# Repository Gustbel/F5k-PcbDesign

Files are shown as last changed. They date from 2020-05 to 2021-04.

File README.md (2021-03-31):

# Diseño en ALTIUM del PCB del FROST5000 - Versión RTM 1.0 #

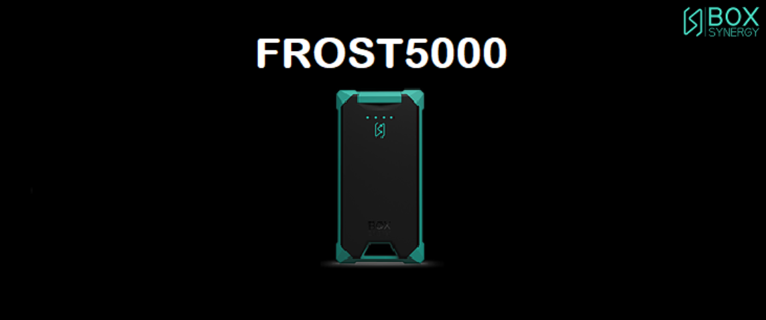
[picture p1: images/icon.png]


## Frost5000 PCB 3D - Versión RTM 1.0 

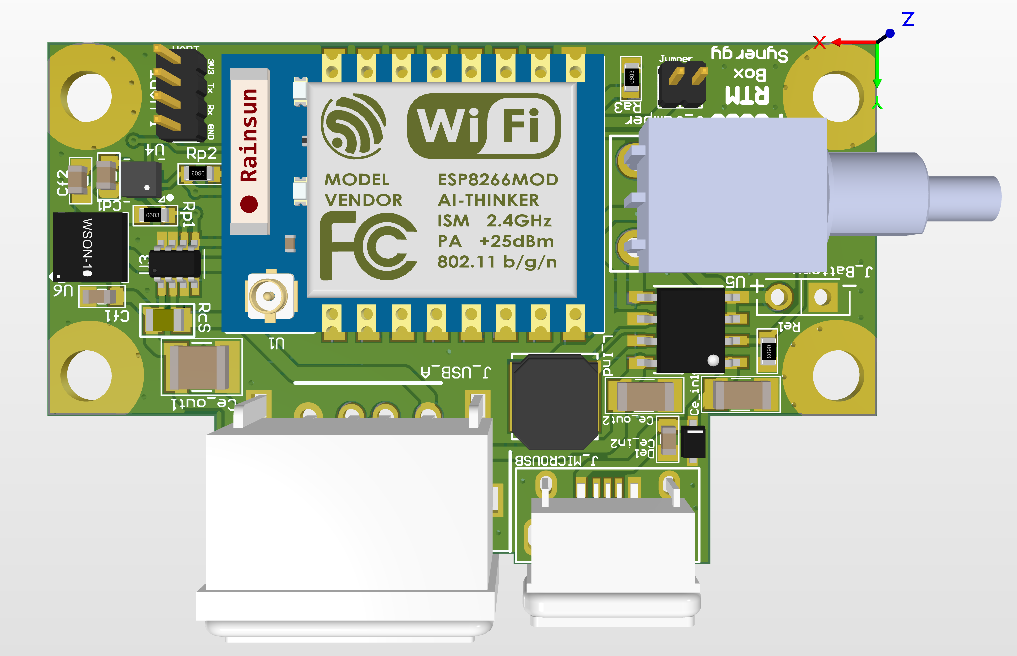
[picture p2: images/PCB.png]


## ¿Para que es este repositorio? 

 - Este repositorio servirá para tener un **Control de Versiones**, **Acceso Remoto al developer** y **Permitir Acceso continuo de avances** al equipo de trabajo de *Box Synergy*.

## ¿Como funciona este repositorio?

Este repositorio tiene dos Branches (o Ramas):

* **master:** Contiene la última versión estable, es decir después de cumplir un objetivo en el diseño y se compruebe que fue estable, se hace un salvado de datos en esta rama. Para consultar avances es preferible mirar esta rama ya que es la más estable.
* **develop:** Contiene la versión que está en desarrollo, por lo tanto probablemente inestable y con errores naturales durante el proceso de desarrollo. Esta rama es la utilizada por el desarrollador y por algún colaborador que quiera mirar o ayudar en pleno desarrollo.

## ¿Como puedo consultar el proyecto?
1. Si no lo tiene, instalar cualquier versión de Altium Designer en su PC.
2. Posicionese en el **BRANCH** (o rama) que usted desee descargar. Para seleccionar el branch haga click en el menú desplegable que está debajo del título del Repositorio (mas específicamente debajo de la descripción del repositorio) y elija el Branch que usted desee.
3. Descargar este repositorio desde un botón con tres puntos **(...)** que se encuentra en la esquina superior derecha del repositorio (al lado del botón *Clone*), luego seleccione ***Download Repository***. Se descargará un archivo comprimido *.zip*.
4. Descomprima la carpeta del Repositorio en alguna carpeta conocida.
5. Abra Altium y seleccione el proyecto que acaba de descomprimir.

## Consultas
- electronic@box-synergy.com	---  Contacto Área Electrónica de Box Synergy
- gustavobelbruno@gmail.com		---  Contacto Gustavo Belbruno - Summits 7 Beta Project Main Designer

																					Repository created 05/04/2020

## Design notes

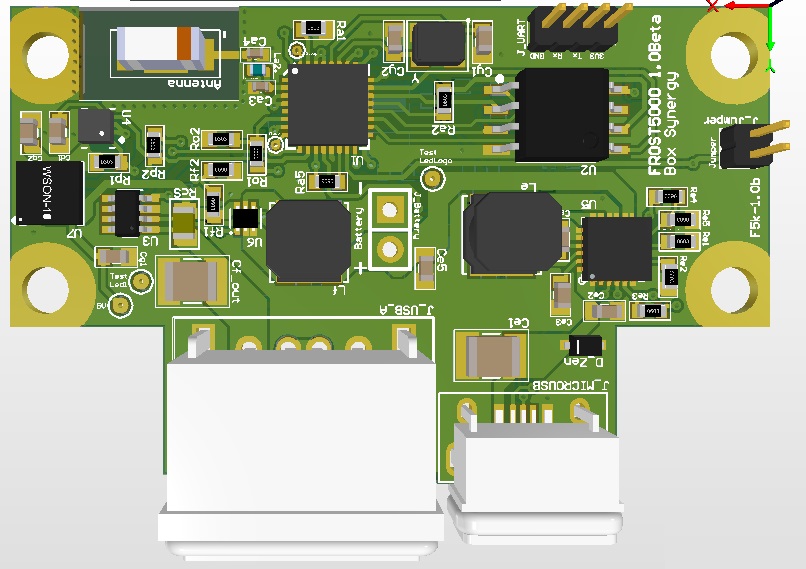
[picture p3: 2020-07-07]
images/PCBFinal_F5k_ConAntenaCeramica.jpg

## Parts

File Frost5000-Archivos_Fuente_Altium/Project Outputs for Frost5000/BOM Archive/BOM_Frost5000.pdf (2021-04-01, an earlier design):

## BOM_Frost5000

1

Component List / BOM Archive | Company: | Box Synergy
Project: | Frost 5000 | Location: | Córdoba, Argentina
Version: | RTM 1.0 | Website: | https://www.box-synergy.com/
Report Date: | 03-29-2021 | Design Engineer Contact: | electronic@box-synergy.com - Gustavo Belbruno
Generated by: | Gustavo Belbruno - Box Synergy Engineering Area
# | Designator | Name/Value | Description | Package / Case | Importance* | Quantity | Manufacturer | Supplier 1 | Alternative Supplier

Name | Part Number | Link Part | Name | Part Number | Link Part
1, 3 | Ca1, Cd1 | 0.1uF | Capac Ceramic SMD 0603 | 0603 | | 2 | - | - | - | - | - | - | -
2 | Ca2 | 10uF | Capac Ceramic SMD 1206 | 1206 | | 1 | - | - | - | - | - | - | -
4, 8, 11 | Ce_bat, Ce_out2, Cf_bat1 | 22uF 10V | Capac Ceramic SMD 1206 | 1206 | | 3 | - | - | - | - | - | - | -
5, 13, 14 | Ce_in1, Cu1, Cu2 | 10uF 10V | Capac Ceramic SMD 1206 | 1206 | | 3 | - | - | - | - | - | - | -
6, 12 | Ce_in2, Cf_bat2 | 100nF 10V | Capac Ceramic SMD 0603 | 0603 | | 2 | - | - | - | - | - | - | -
7 | Ce_out1 | 22uF 10V | Capac Ceramic SMD 1210 | 1210 | | 1 | - | - | - | - | - | - | -
9 | Cf1 | 22uF 10V | Capac Ceramic SMD 0603 | 0603 | | 1 | - | - | - | - | - | - | -
10 | Cf2 | 22uF | Capac Ceramic SMD 0603 | 0603 | | 1 | - | - | - | - | - | - | -
37 | Rd1 | 4.7K | Resistor SMD | 0603 | | 1 | - | - | - | - | - | - | -
33, 34, 35, 38, 44 | Ra1, Ra2, Ra3, Re1, Rpb1 | 5.6K | Resistor SMD | 0603 | | 5 | - | - | - | - | - | - | -
45, 47, 49, 51, 53 | Rq1b, Rq2b, Rq3b, Rq4b, Rq5b | 1K | Resistor SMD | 0603 | | 5 | - | - | - | - | - | - | -
39, 55 | Rf_in1, Ru | 0 Ohms | Resistor SMD | 0603 | | 2 | - | - | - | - | - | - | -
40 | Ro1 | 332K +-1% | Resistor SMD | 0603 | | 1 | - | - | - | - | - | - | -
41 | Ro2 | 90.9K +- 1% | Resistor SMD | 0603 | | 1 | - | - | - | - | - | - | -
42, 43 | Rp1, Rp2 | 10K | Resistor SMD | 0603 | | 2 | - | - | - | - | - | - | -
46, 48, 50, 52, 54 | Rq1c, Rq2c, Rq3c, Rq4c, Rq5c | 2.74K | Resistor SMD | 0603 | | 5 | - | - | - | - | - | - | -
36 | RcS | ERJ-6BWFR010V | Shunt 0.01 Ohm 0.5W 1% SMD Resistor | 0805 | Important Good Quality, at least 0.5W | 1 | Panasonic | Mouser | 667-ERJ-6BWFR010V | Link Mouser (https://www.mouser.com/ProductDetail/Panasonic/ERJ-6BWFR010V) | Digikey | P.01AQTR-ND | Link Digikey (https://www.digikey.com/product-detail/en/panasonic-electronic-components/ERJ-6BWFR010V/P-01AQTR-ND/1466354)
26 | L_Ind | SRN5040TA-1R0M | Inductor 1uH 5A | Non Standard | Important Good Quality, 1uH Value, at least 5A | 1 | Bourns | Mouser | 652-SRN5040TA-1R0M | Link Mouser (https://www.mouser.com/ProductDetail/Bourns/SRN5040TA-1R0M) | Digikey | SRN5040TA-1R0MCT-ND | Link Digikey (https://www.digikey.com/product-detail/en/bourns-inc/SRN5040TA-1R0M/SRN5040TA-1R0MCT-ND/9653900)
22 | J_Jumper | M50-3530242 | 1.27mm Pin Header 2x1 | 1.27mm Header | | 1 | HARWIN | Mouser | 855-M50-3530242 | Link Mouser (https://www.mouser.com/ProductDetail/Harwin/M50-3530242?qs=%252BdQmOuGyFcFfqfwYQe%2FxZw%3D%3D) | - | - | -
24 | J_UART | M50-3530442 | 1.27mm Pin Header 4x1 | 1.27mm Header | | 1 | HARWIN | Mouser | 855-M50-3530442 | Link Mouser (https://www.mouser.com/ProductDetail/Harwin/M50-3530242?qs=%252BdQmOuGyFcFfqfwYQe%2FxZw%3D%3D) | - | - | -
23 | J_MICROUSB | CQ-MUB-FS8772 | MicroUSB B-type Socket | - | | 1 | Shenzhen Chuangqin Technology | Alibaba | - | Link Alibaba (https://www.alibaba.com/product-detail/Rating-3-AMP-Micro-usb-Jack_60827902326.html) | - | - | -
25 | J_USB_A | CQ-USB-AFFS90 | USB-A Socket | - | | 1 | Shenzhen Chuangqin Technology | Alibaba | - | Link Alibaba (https://www.alibaba.com/product-detail/4-Pin-Waterproof-IPX8-USB-A_62420880597.html) | - | - | -
15, 16, 17, 18, 19 | D_LED1, D_LED2, D_LED3, D_LED4, D_LED5 | LCB TTSD-T2V1-2J8L-Z | Blue LED PLCC-2 | PLCC-2 | | 5 | OSRAM | Mouser | 720-LCBTTSDT2VA116 0 | Link Mouser (https://www.mouser.com/ProductDetail/OSRAM-Opto-Semiconductors/LCB-TTSD-T2V1-2J8L-Z) | - | - | -
20 | De1 | DDZ6V8BSF-7 | Zener 6.5V / 0.5W | SOD323F | | 3 | Diodes | Mouser | 621-DDZ6V8BSF-7 | Link Mouser (https://www.mouser.com/ProductDetail/Diodes-Incorporated/DDZ6V8BSF-7/) | Digikey | DDZ6V8BSF-7 | Link Digikey (https://www.digikey.com/en/products/detail/DDZ6V8BSF-7/DDZ6V8BSF-7DICT-ND/2921380)
28, 29, 30 | Q1, Q2, Q3 | BC817 | Transistor NPN | SOT-23-3 | | 3 | Diodes | Mouser | 621-BC817-40W-7 | Link Mouser (https://www.mouser.com/ProductDetail/Diodes-Incorporated/BC817-40W-7/) | Digikey | BC817-40W-7 | Link Digikey (https://www.digikey.com/en/products/detail/BC817-40W-7/BC817-40WDICT-ND/816560)
31, 32 | Q4, Q5 | BC807 | Transistor PNP | SOT-23-3 | | 2 | Diodes | Mouser | 621-BC807-40-7-F | Link Mouser (https://www.mouser.com/ProductDetail/Diodes-Incorporated/BC807-40-7-F/?qs=rGAXPo9uwV2n5WQ1Pm08Rg%3D%3D) | Digikey | BC807-40-7-F | Link Digikey (https://www.digikey.com/en/products/detail/BC807-40-7-F/BC807-40FCT-ND/717840)
56 | U1 | ESP-07 | ESP07 Module with Antenna Ai-Thinker | - | | 1 | Ai-Thinker | Alibaba | - | Link Alibaba (https://www.alibaba.com/product-detail/Ai-Thinker-ESP-07-ESP8266-Wifi_62009924257.html) | It can be easily found with others Alibaba sellers

## BOM_Frost5000

2

57 | U2 | 24CW1280T-I/OT | EEPROM 128K I2C | SOT-23-5 | 1 | Microchip | Mouser | 579-24CW1280T-I/OT | Link Mouser (https://www.mouser.com/ProductDetail/Microchip-Technology/24CW1280T-I-OT?qs=qSfuJ%252Bfl%2Fd6lIWZGGRvkYA==) | Digikey | 24CW1280T-I/OTCT-ND | Link Digikey (https://www.digikey.com/product-detail/en/microchip-technology/24CW1280T-I-OT/24CW1280T-I-OTCT-ND/9607061)
58 | U3 | INA219BIDCNR | Current Monitor Regulator High-Side 10mA SOT-23-8 | SOT-23-8 | 1 | Texas Instruments | Mouser | 595-INA219BIDCNR | Link Mouser (https://www.mouser.com/ProductDetail/Texas-Instruments/INA219BIDCNR) | Digikey | 296-46420-1-ND | Link Digikey (https://www.digikey.com/product-detail/en/texas-instruments/INA219BIDCNR/296-46420-1-ND/7033594)
59 | U4 | MC3419 | Accelerometer | VFLGA-12 | 1 | MEMSIC | Mouser | 498-MC3419 | Link Mouser (https://www.mouser.com/ProductDetail/MEMSIC/MC3419/?qs=OlC7AqGiEDn8kT%252B18r9wSA%3D%3D) | - | - | -
60 | U5 | FM5324G | Power Battery Management IC | eSOP8L | 1 | FM Shenzen | Yoycart | FM5324G | Link Yoycart (https://www.yoycart.com/Product/630728961250/) | - | - | -
61 | U6 | LM1117LD-3.3/NOPB | LDO Regulator Pos 3.3V 0.8A Texas - WSON8 | WSON8 | 1 | Texas Instruments | Mouser | 926-LM1117LD33NOPB | Link Mouser (https://www.mouser.com/ProductDetail/Texas-Instruments/LM1117LD-33-NOPB) | Digikey | LM1117LD-3.3 /NOPBCT-ND | Link Digikey (https://www.digikey.com/product-detail/en/texas-instruments/LM1117LD-3-3-NOPB/LM1117LD-3-3-NOPBCT-ND/3527179)
27 | PB1 | 800SP9B7M6RE | Push Button 800C | M6 | 1 | E-Switch | Mouser | 612-800-S762 | Link Mouser (https://www.mouser.com/ProductDetail/E-Switch/800SP9B7M6RE) | onlinecomponents.com | 800SP9B7M6RE | Link OC (https://www.onlinecomponents.com/en/e-switch/800sp9b7m6re-11259284.html)
21 | J_Battery | Connx2_Battery | No component
*Importance: Refers to the importance of using the designated component and not a default replacement | This is a critical device and was specially calculated, it should not be exchanged for any device. In case of not obtaining this device, please contact the design engineer.
| If possible, use the supplied device. In case there is difficulty in obtaining it, you can use another one with similar characteristics, but as long as the device has a complete datasheet where its parameters can be consulted.
| This is a regular device and you can choose the device that suits you.

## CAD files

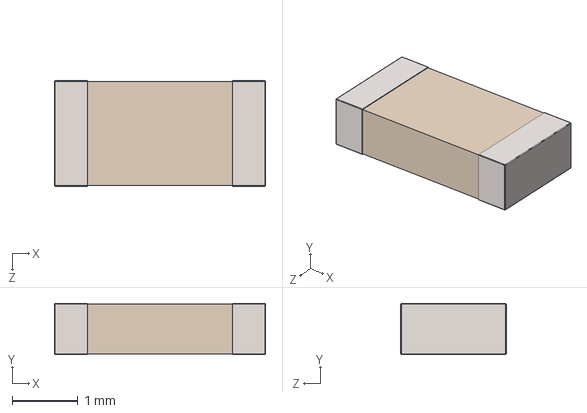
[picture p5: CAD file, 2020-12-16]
Frost5000-Archivos_Fuente_Altium/LibraryUsed/Originales/STEP_Models/Cap1206.step
3.20 x 0.78 x 1.60 mm

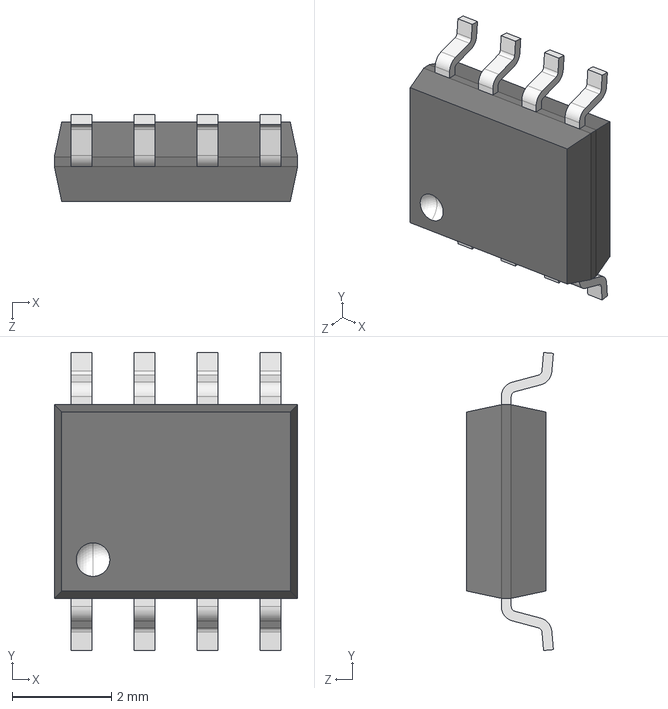
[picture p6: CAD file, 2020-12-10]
Frost5000-Archivos_Fuente_Altium/LibraryUsed/Originales/STEP_Models/SOP8.step
4.90 x 6.00 x 1.75 mm

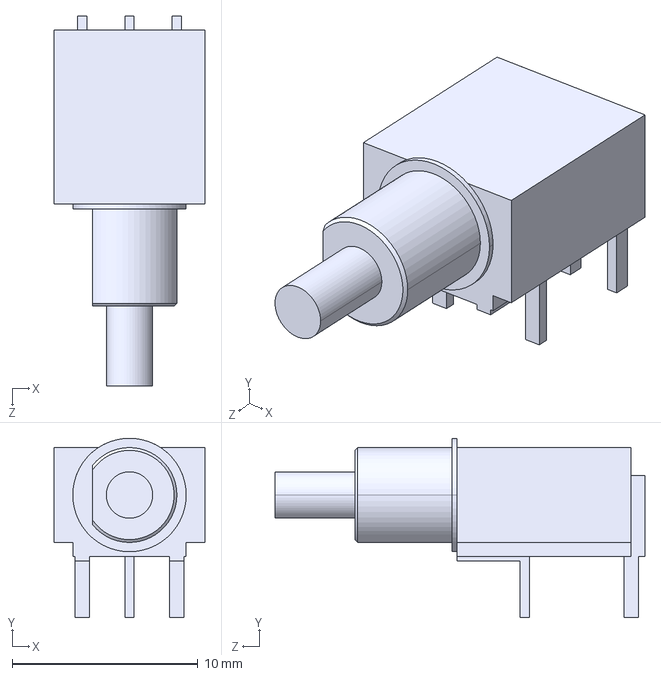
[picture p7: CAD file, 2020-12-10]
Frost5000-Archivos_Fuente_Altium/LibraryUsed/Originales/STEP_Models/Push_800C.STEP
8.10 x 9.65 x 19.9 mm

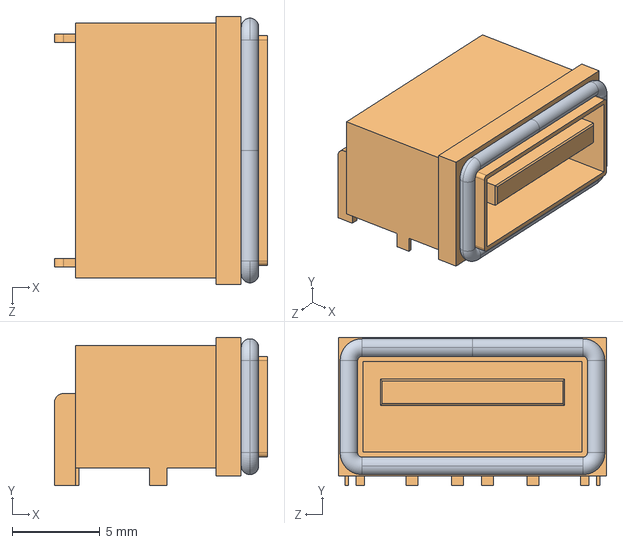
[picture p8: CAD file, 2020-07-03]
Frost5000-Archivos_Fuente_Altium/LibraryUsed/Originales/STEP_Models/USB_A_ip68.STEP
12.1 x 8.45 x 15.3 mm

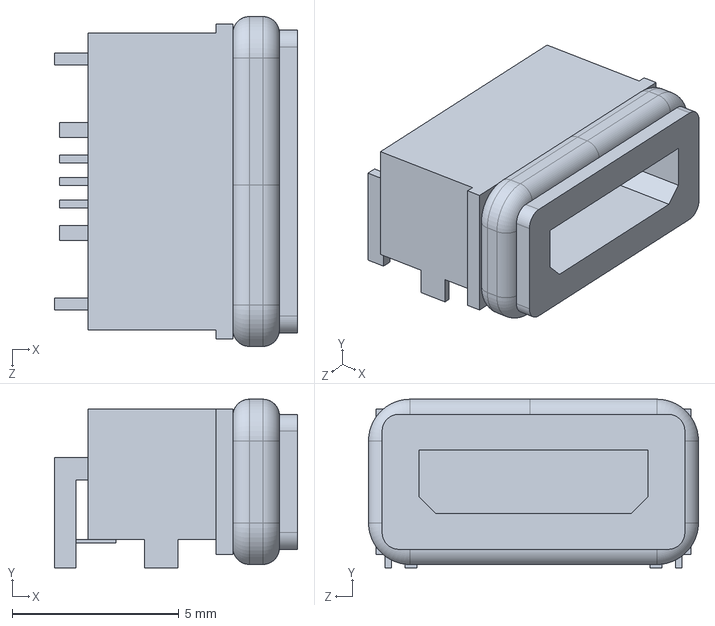
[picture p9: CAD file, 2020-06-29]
Frost5000-Archivos_Fuente_Altium/LibraryUsed/Originales/STEP_Models/MicroUSBip68.STEP
7.29 x 5.06 x 9.90 mm

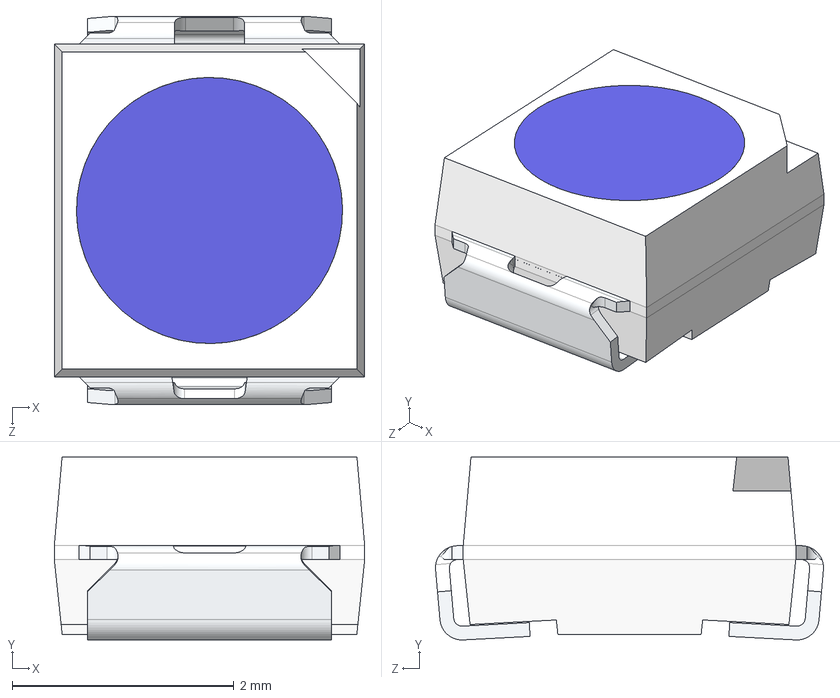
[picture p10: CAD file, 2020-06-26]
Frost5000-Archivos_Fuente_Altium/LibraryUsed/Originales/STEP_Models/LED_PLCC-2.STEP
2.80 x 1.65 x 3.50 mm
PLCC2-Case
TEIL1.stp
LFR1
LFR2

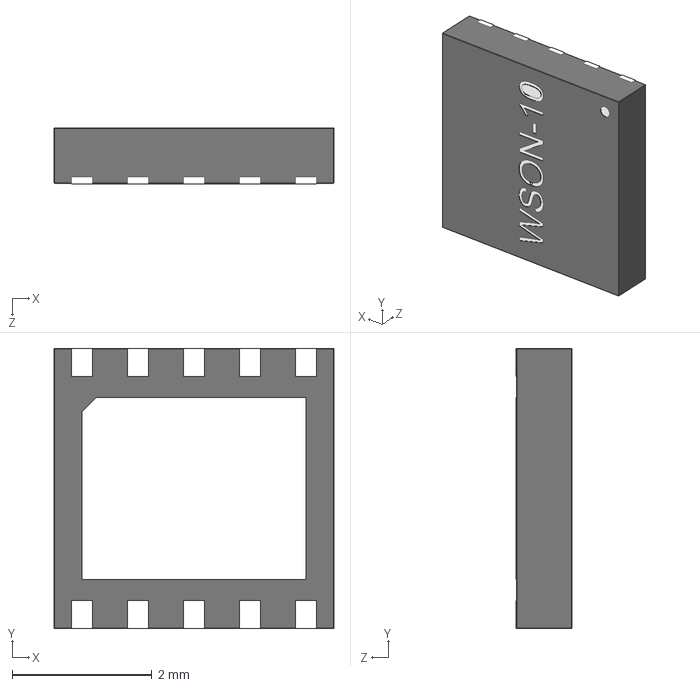
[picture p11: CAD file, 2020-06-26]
Frost5000-Archivos_Fuente_Altium/LibraryUsed/Originales/STEP_Models/LM1117-33-WSON.STEP
4.00 x 4.00 x 0.8 mm

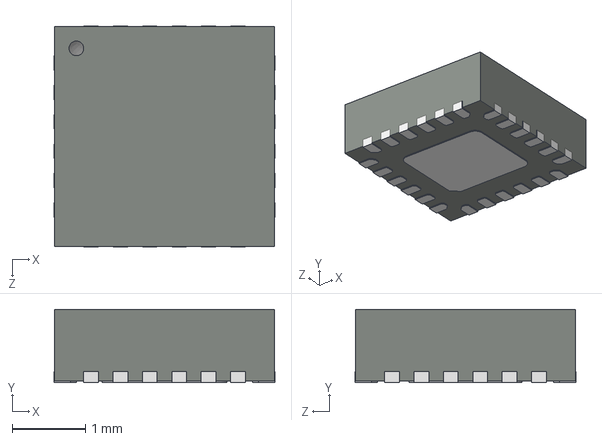
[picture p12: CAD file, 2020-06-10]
Frost5000-Archivos_Fuente_Altium/LibraryUsed/Originales/STEP_Models/ICM-20948.step
3.01 x 1.00 x 3.01 mm

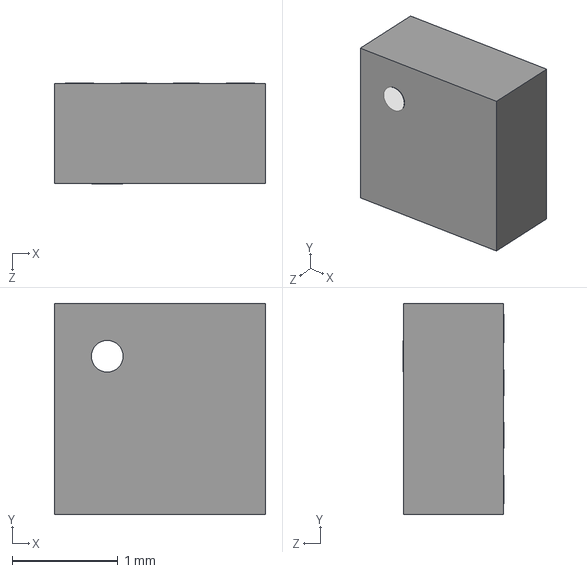
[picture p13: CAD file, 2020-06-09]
Frost5000-Archivos_Fuente_Altium/LibraryUsed/Originales/STEP_Models/LSM303AGR-LGA12.step
2.00 x 2.00 x 0.955 mm

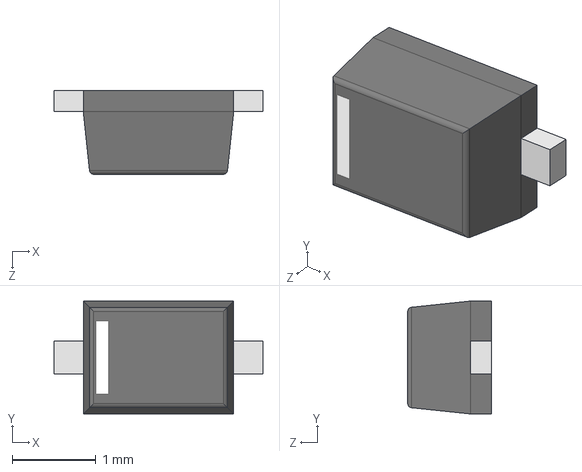
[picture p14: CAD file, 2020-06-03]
Frost5000-Archivos_Fuente_Altium/LibraryUsed/Originales/STEP_Models/Zener-SOD323F.step
2.50 x 1.35 x 1.00 mm

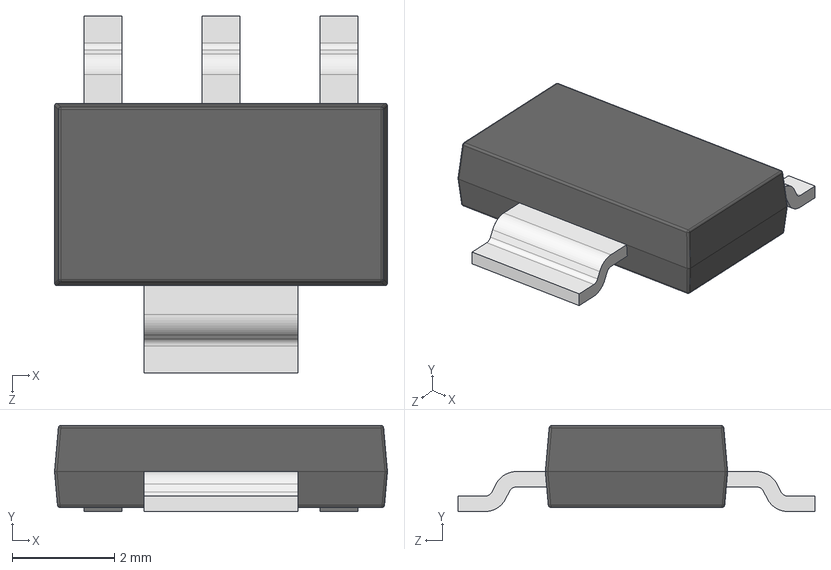
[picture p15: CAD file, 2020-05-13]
Frost5000-Archivos_Fuente_Altium/LibraryUsed/Originales/STEP_Models/LT1171ST-3V3_SOT223.STEP
6.50 x 1.68 x 6.96 mm

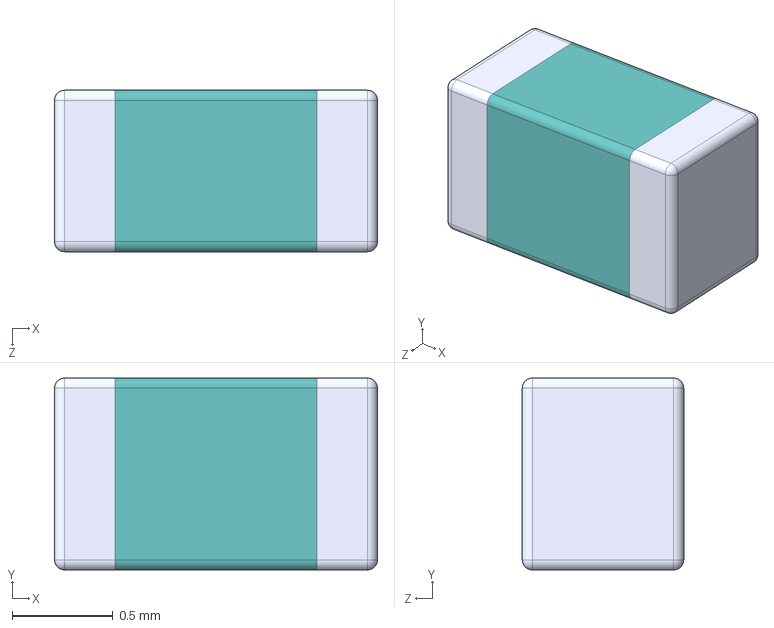
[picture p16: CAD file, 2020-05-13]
Frost5000-Archivos_Fuente_Altium/LibraryUsed/Originales/STEP_Models/Ind0603.step
1.60 x 0.95 x 0.8 mm

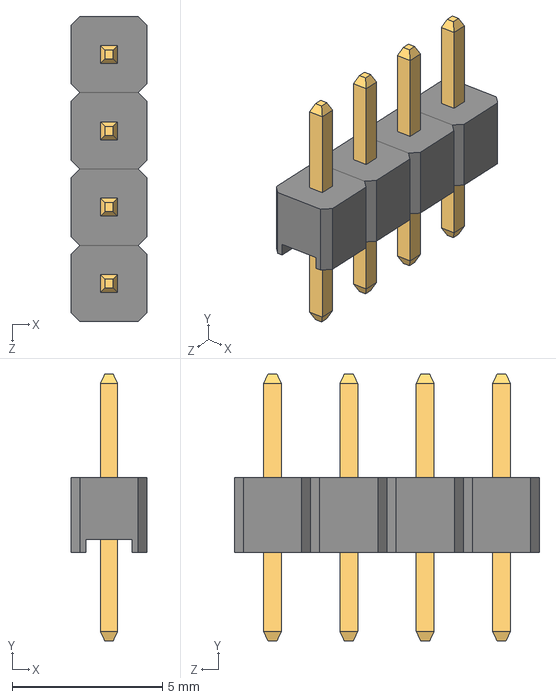
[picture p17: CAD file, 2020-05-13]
Frost5000-Archivos_Fuente_Altium/LibraryUsed/Originales/STEP_Models/Header_254mm_Pitch4-1.step
2.54 x 8.88 x 10.2 mm

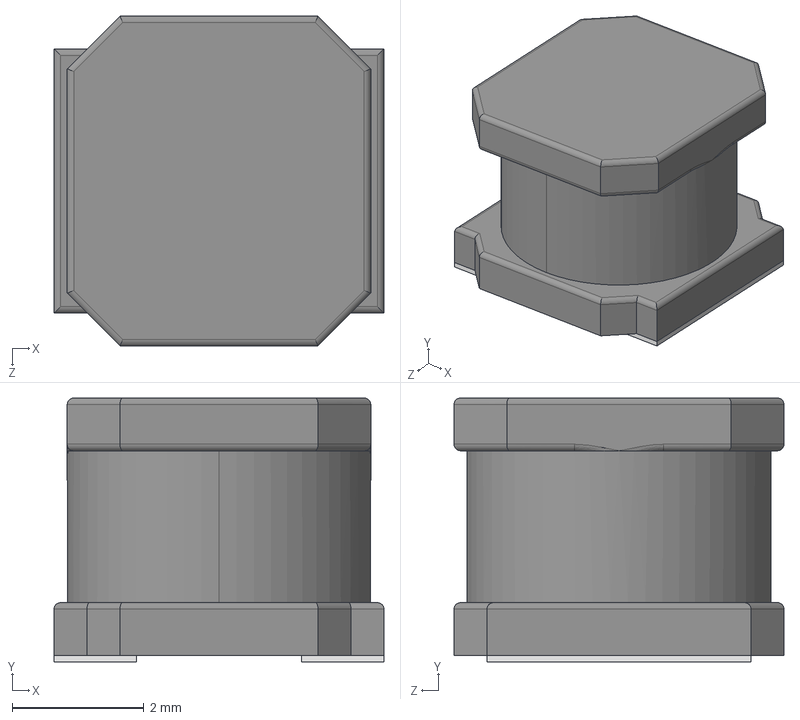
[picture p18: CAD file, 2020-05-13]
Frost5000-Archivos_Fuente_Altium/LibraryUsed/Originales/STEP_Models/Inductor_Buck_SRN5040.step
5.00 x 4.00 x 5.00 mm

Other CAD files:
Frost5000-Archivos_Fuente_Altium/LibraryUsed/Originales/STEP_Models/Cap1210.step
Frost5000-Archivos_Fuente_Altium/LibraryUsed/Originales/STEP_Models/W25Q32JV_SOIC-8-208.STEP
Frost5000-Archivos_Fuente_Altium/LibraryUsed/Originales/STEP_Models/ABM8-26MHz.STEP
Frost5000-Archivos_Fuente_Altium/LibraryUsed/Originales/STEP_Models/Header_127mm_Pitch2-1_usar2.step
Frost5000-Archivos_Fuente_Altium/LibraryUsed/Originales/STEP_Models/BQ25606-VQFN24.step
Frost5000-Archivos_Fuente_Altium/LibraryUsed/Originales/STEP_Models/Cap0603.step
Frost5000-Archivos_Fuente_Altium/LibraryUsed/Originales/STEP_Models/ESP8266EX.STEP
Frost5000-Archivos_Fuente_Altium/LibraryUsed/Originales/STEP_Models/Header_254mm_Pitch2-1.step
Frost5000-Archivos_Fuente_Altium/LibraryUsed/Originales/STEP_Models/INA219_SOT23.STEP
Frost5000-Archivos_Fuente_Altium/LibraryUsed/Originales/STEP_Models/LED_HSMW-C191.STEP
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

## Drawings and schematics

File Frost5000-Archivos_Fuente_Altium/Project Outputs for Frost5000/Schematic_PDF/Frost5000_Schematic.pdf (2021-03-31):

# Current Monitor of USBout

# INA219BIDCNR

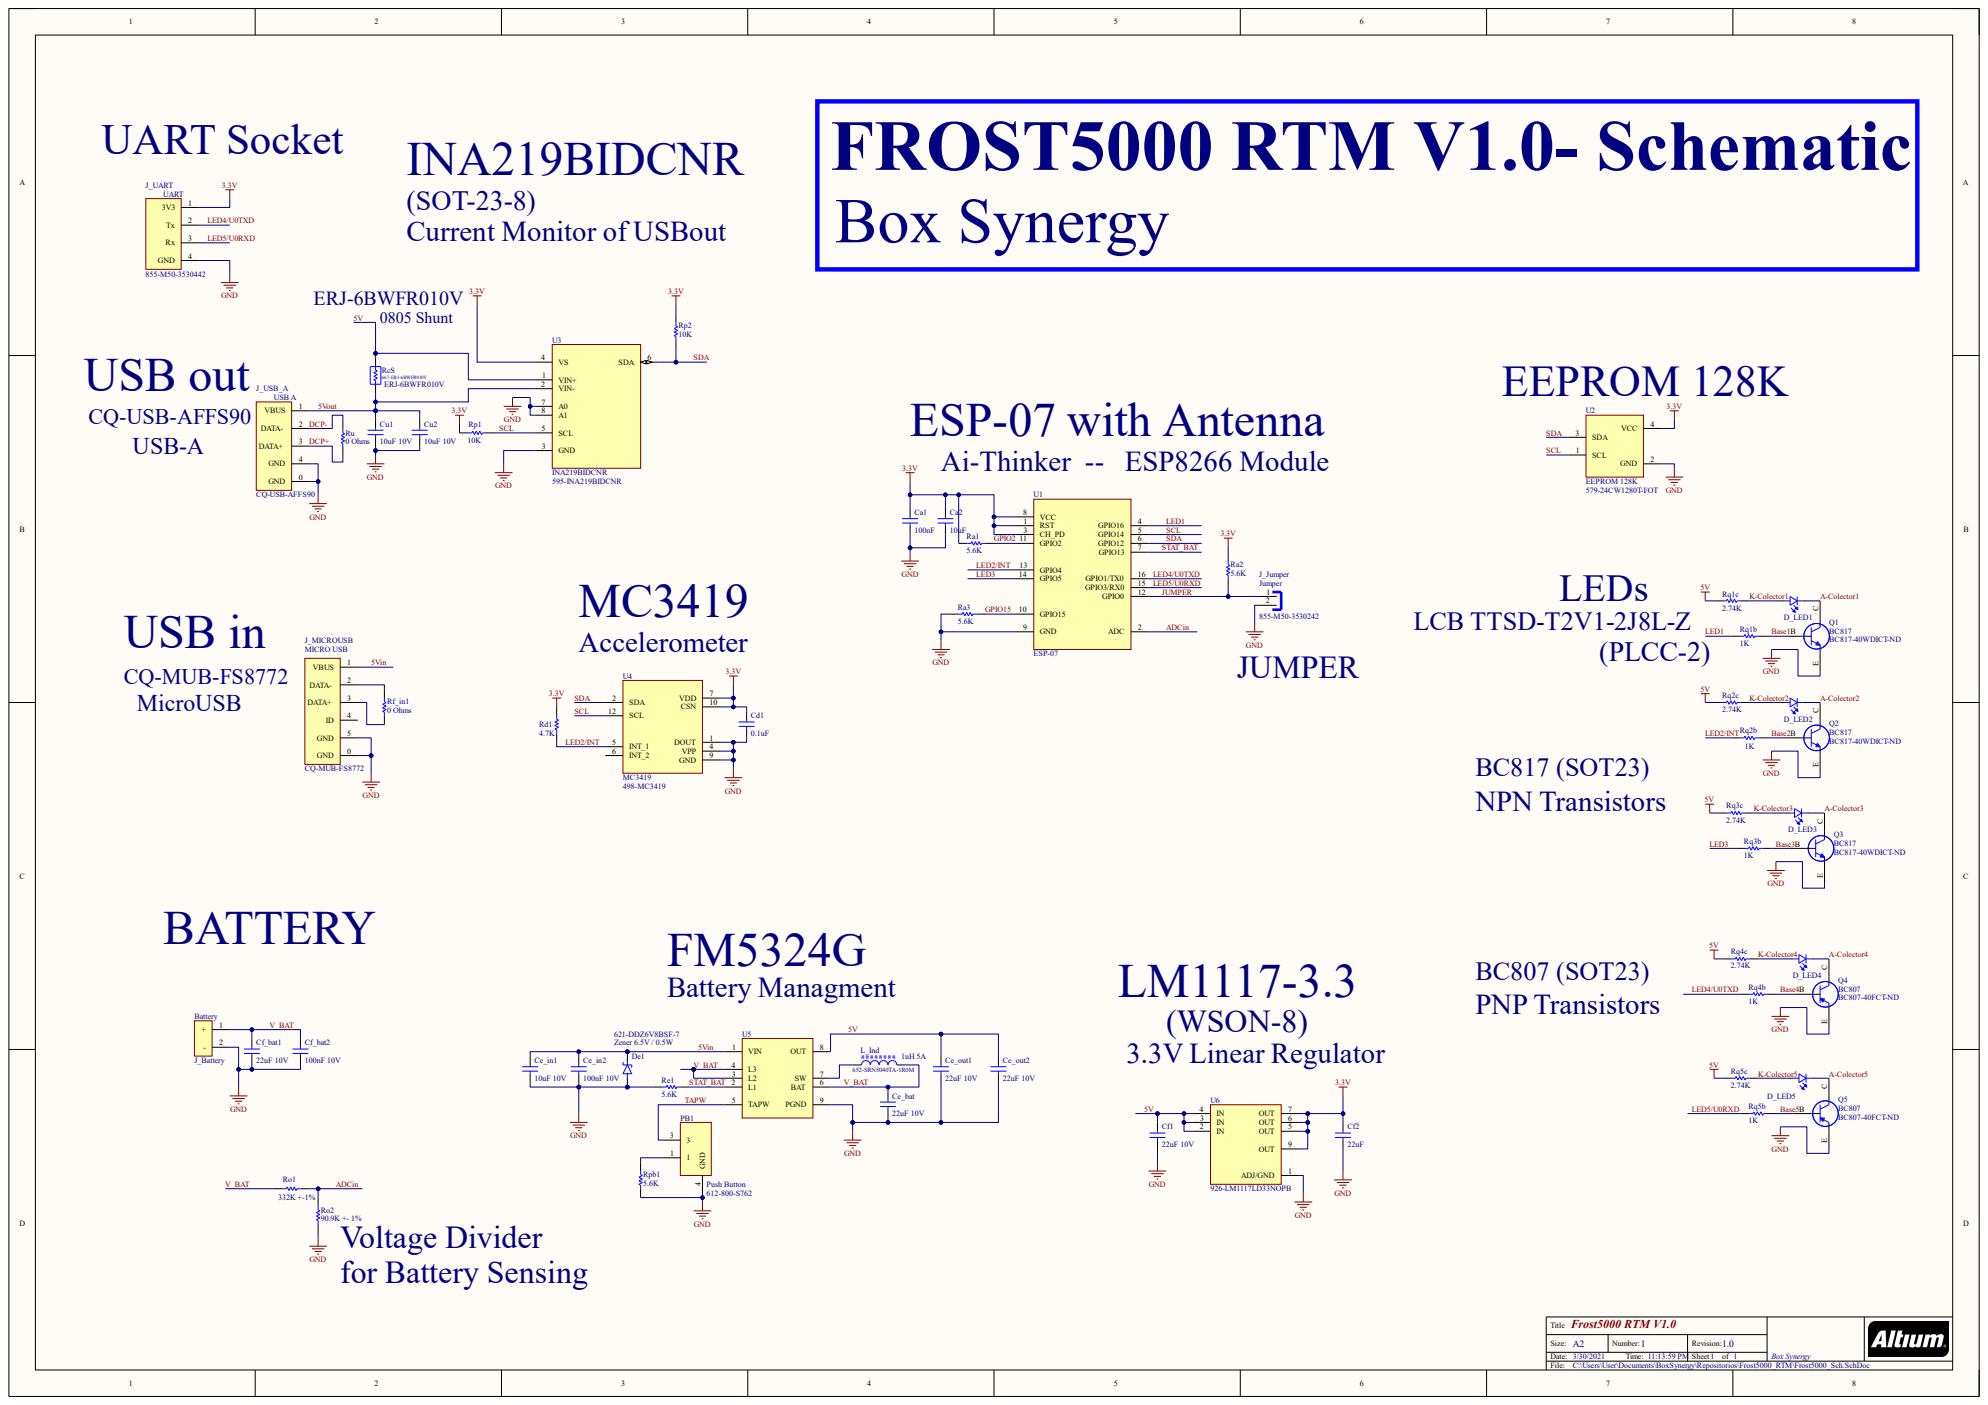
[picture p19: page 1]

Frost5000 RTM V1.0
Title
C:\Users\User\Documents\BoxSynergy\Repositorios\Frost5000_RTM\Frost5000_Sch.SchDoc

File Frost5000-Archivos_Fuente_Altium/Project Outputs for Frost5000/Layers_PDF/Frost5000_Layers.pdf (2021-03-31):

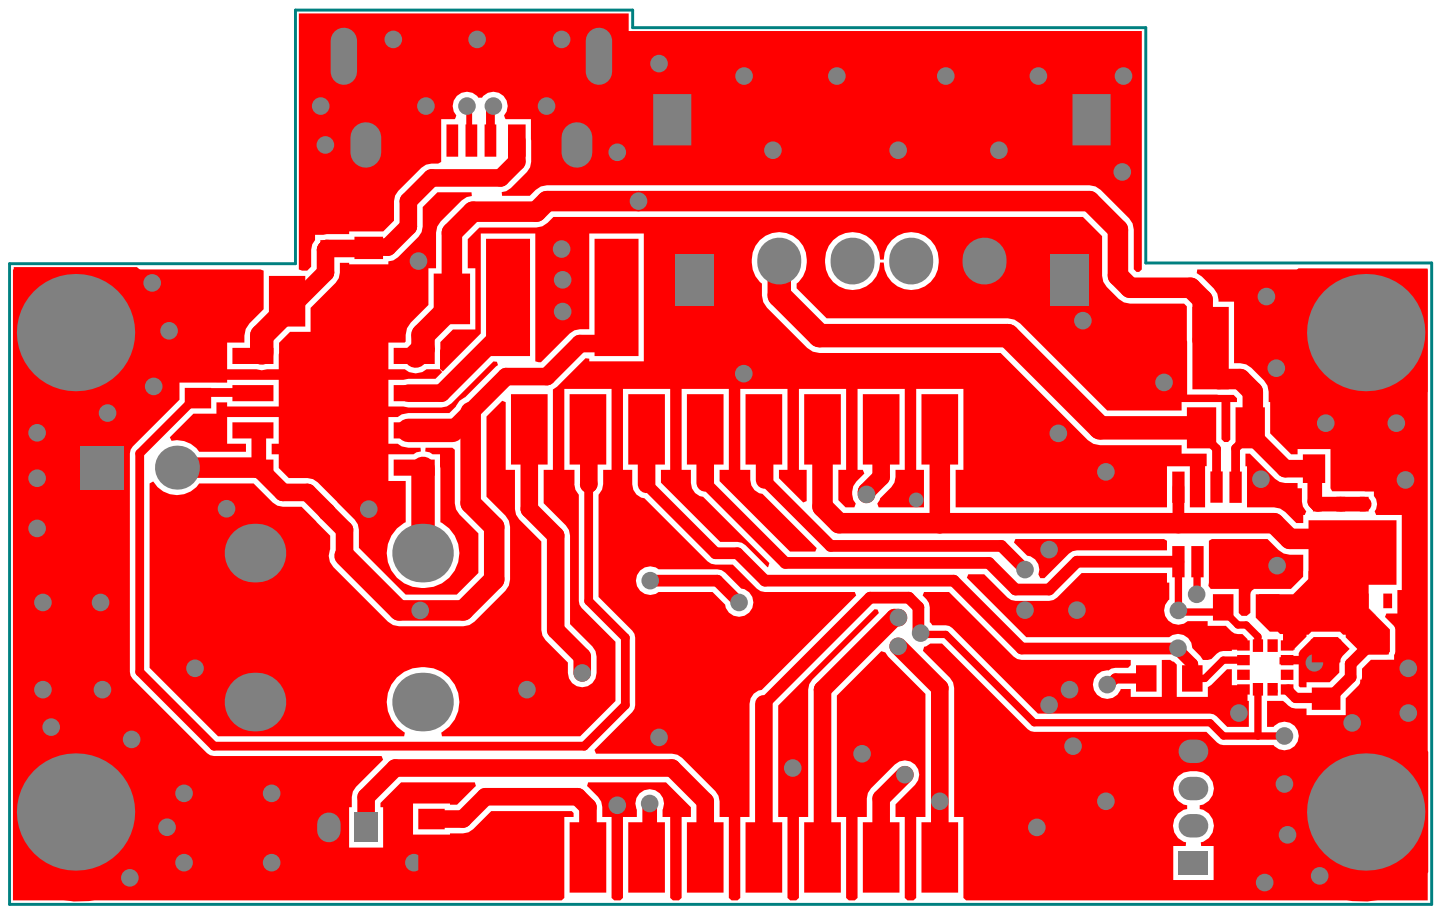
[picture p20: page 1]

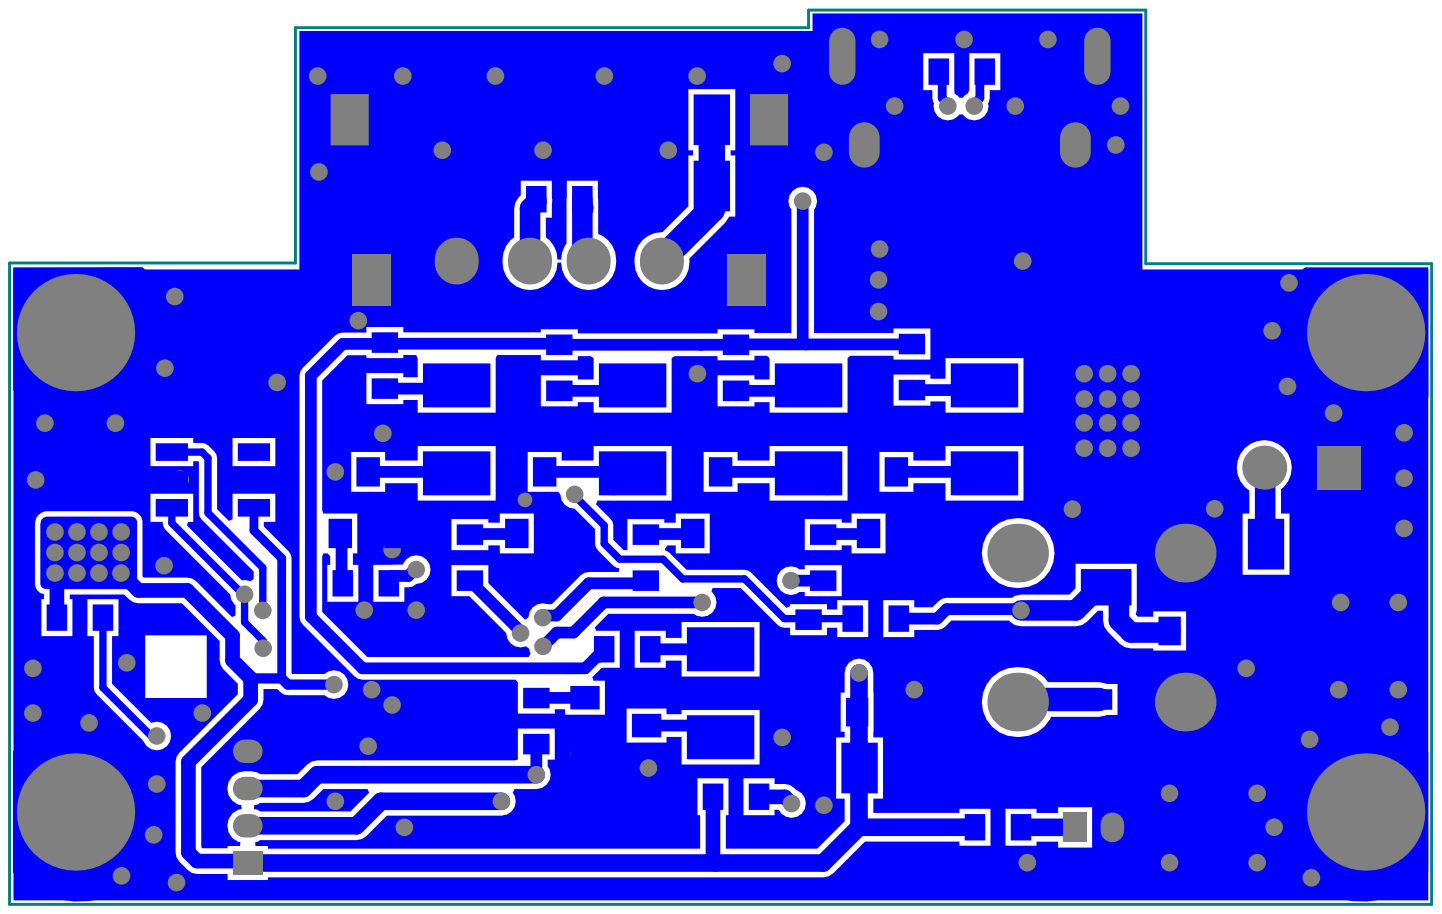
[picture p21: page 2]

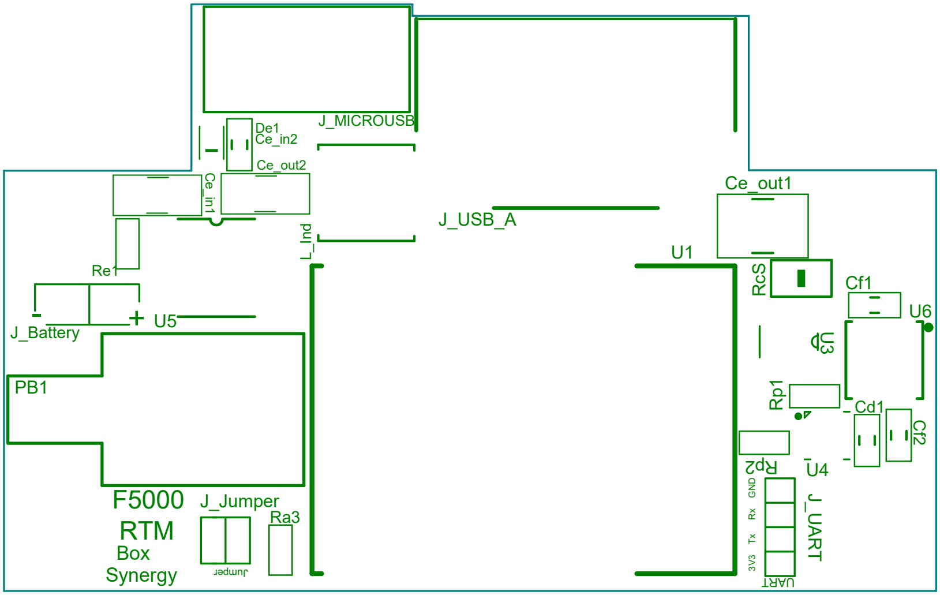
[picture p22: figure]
3V³ Rx GND; Ce_out2; J_Jumper Ce_in1; Ce_out1; J_Battery; J_MICROUSB; F5000 RTM; J_USB_A; Box Synergy
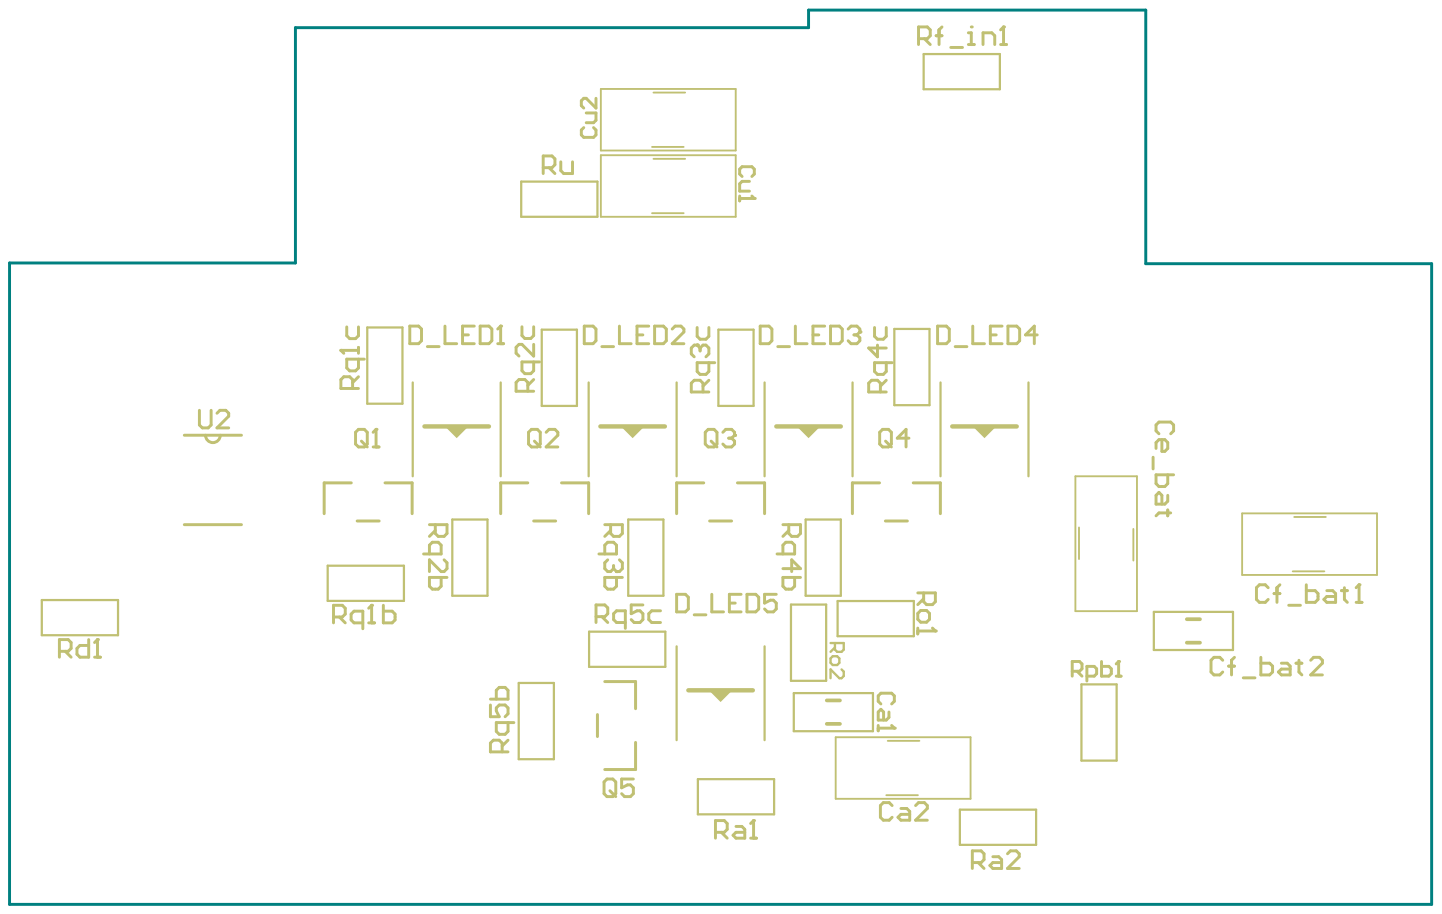
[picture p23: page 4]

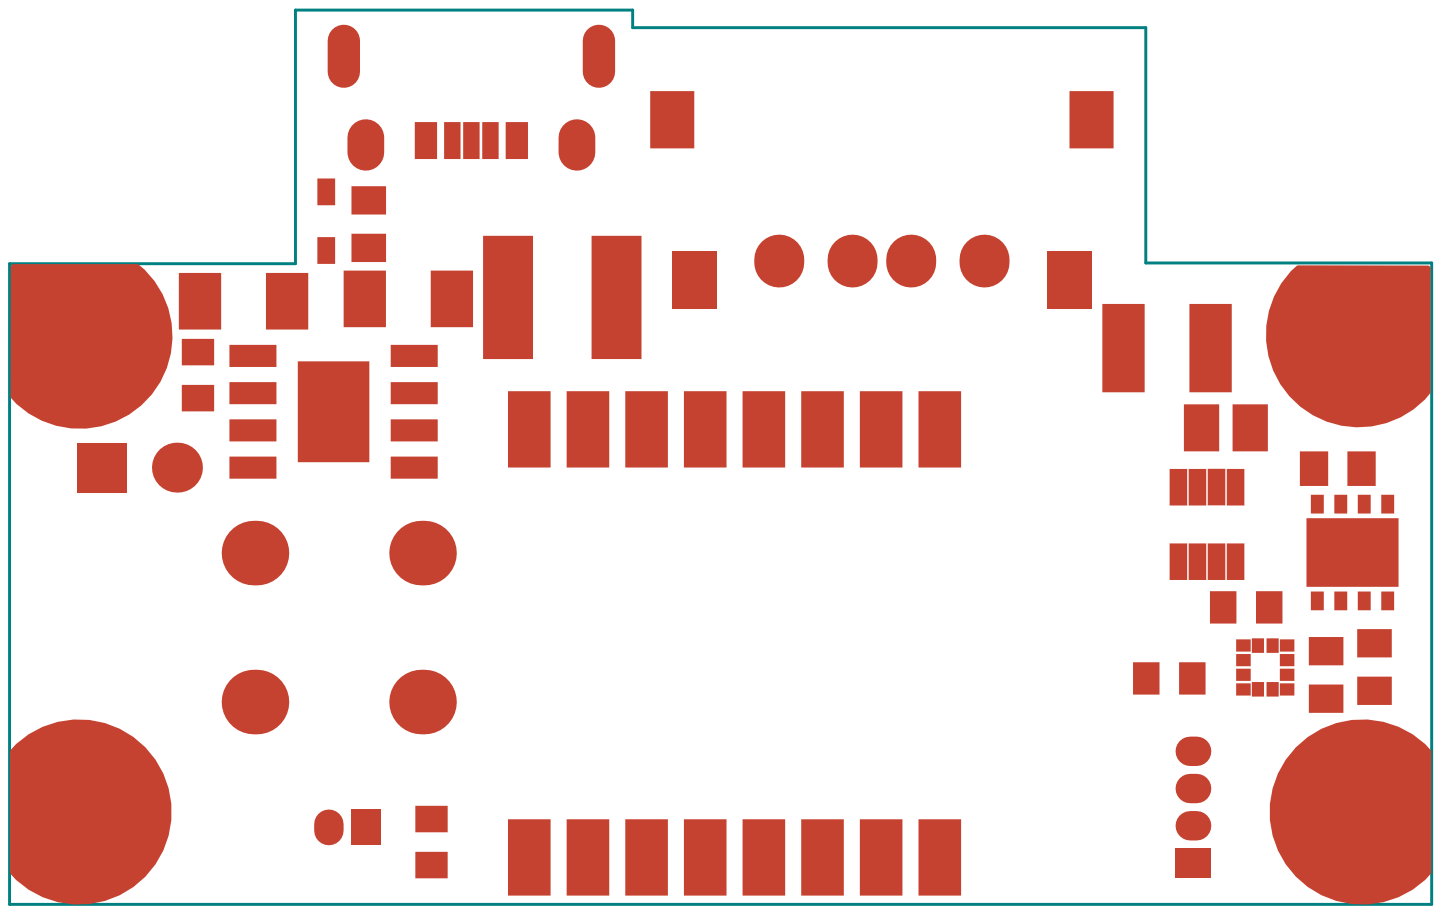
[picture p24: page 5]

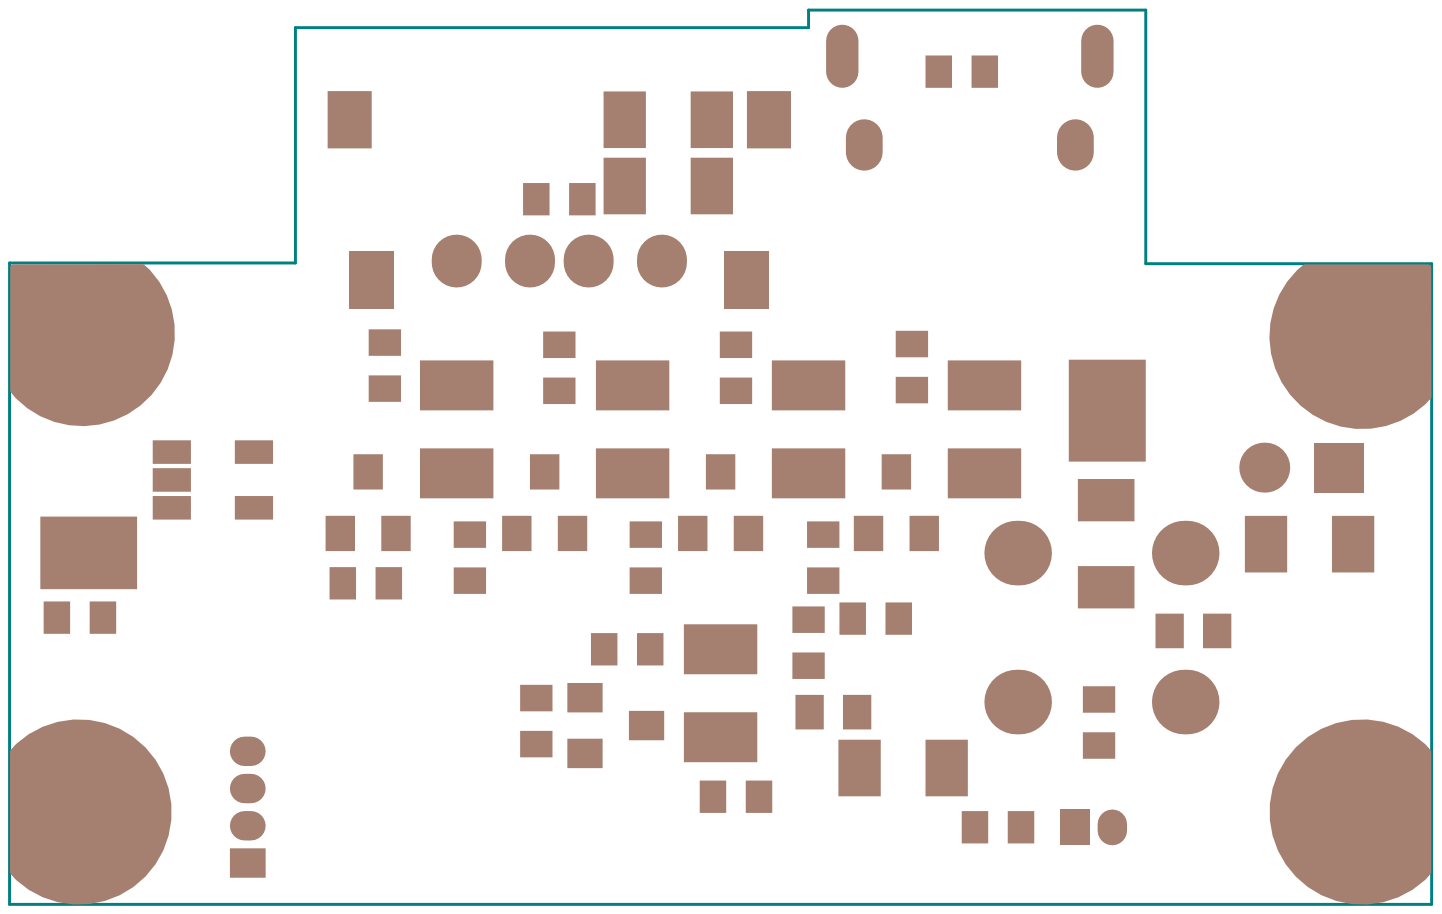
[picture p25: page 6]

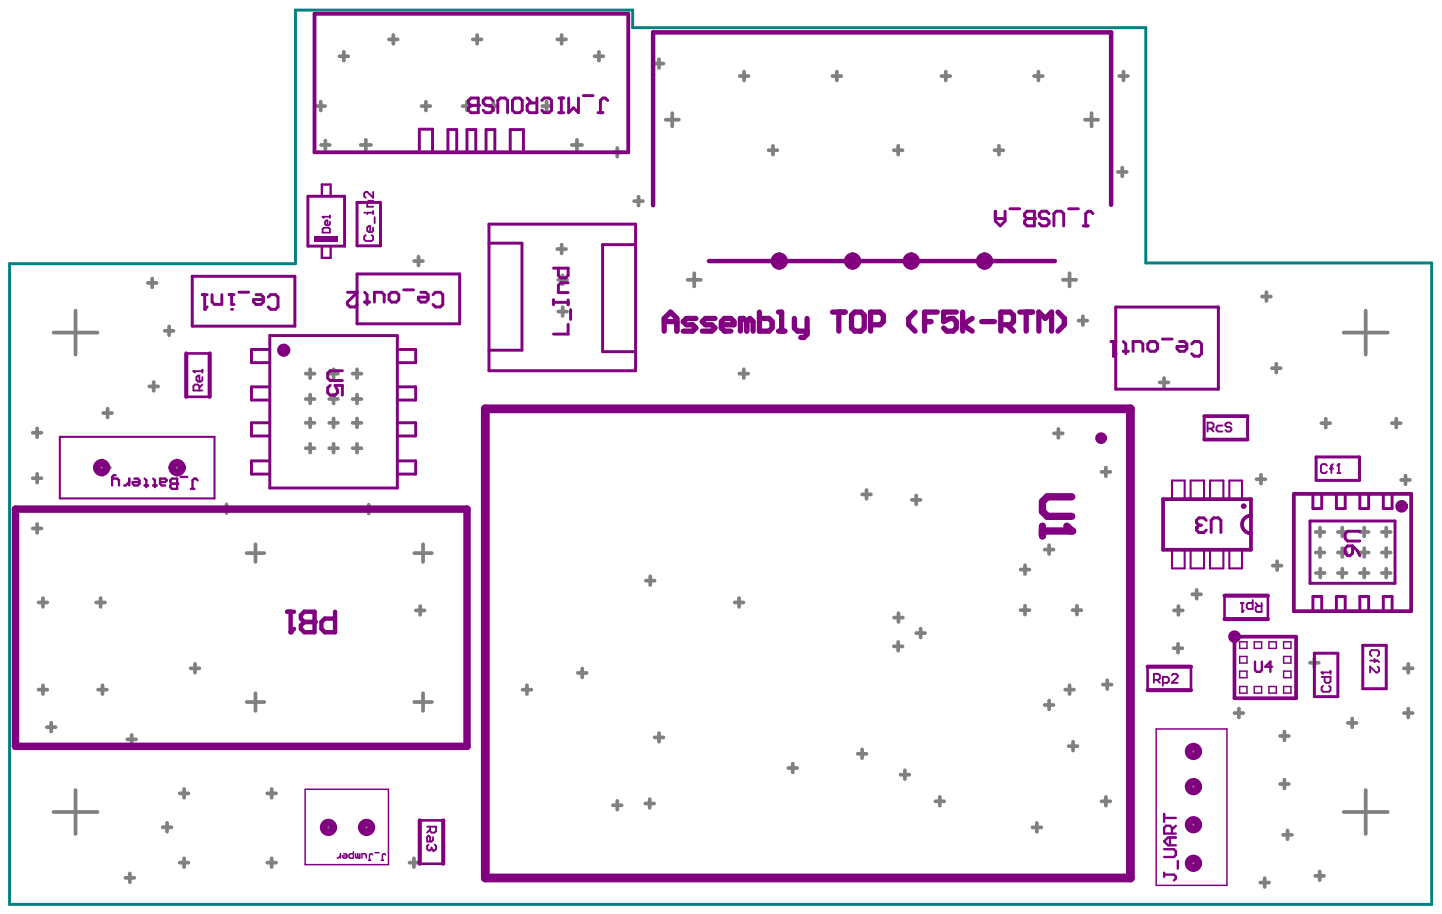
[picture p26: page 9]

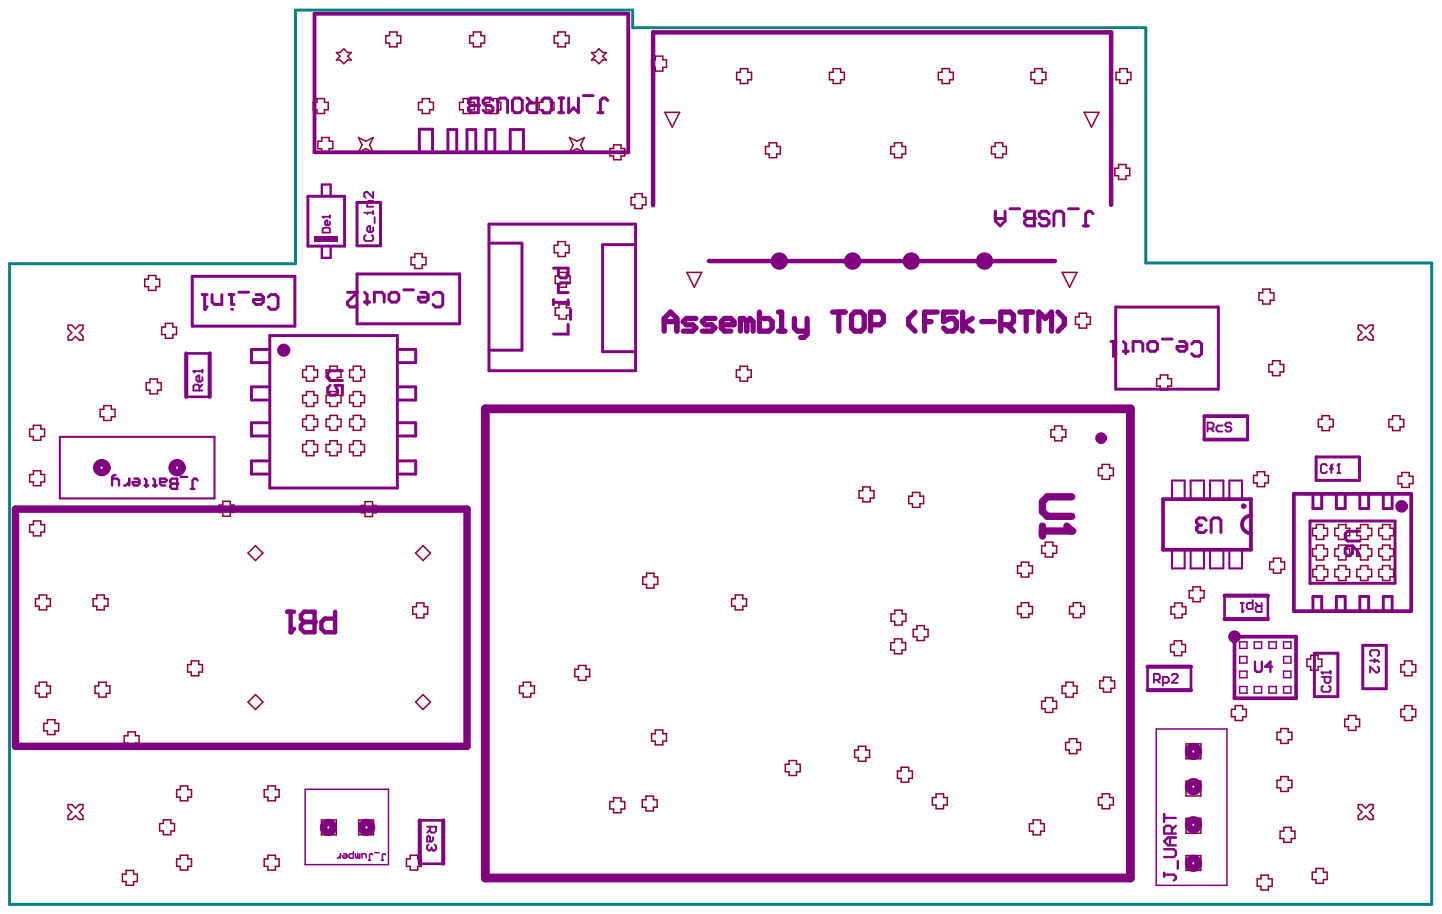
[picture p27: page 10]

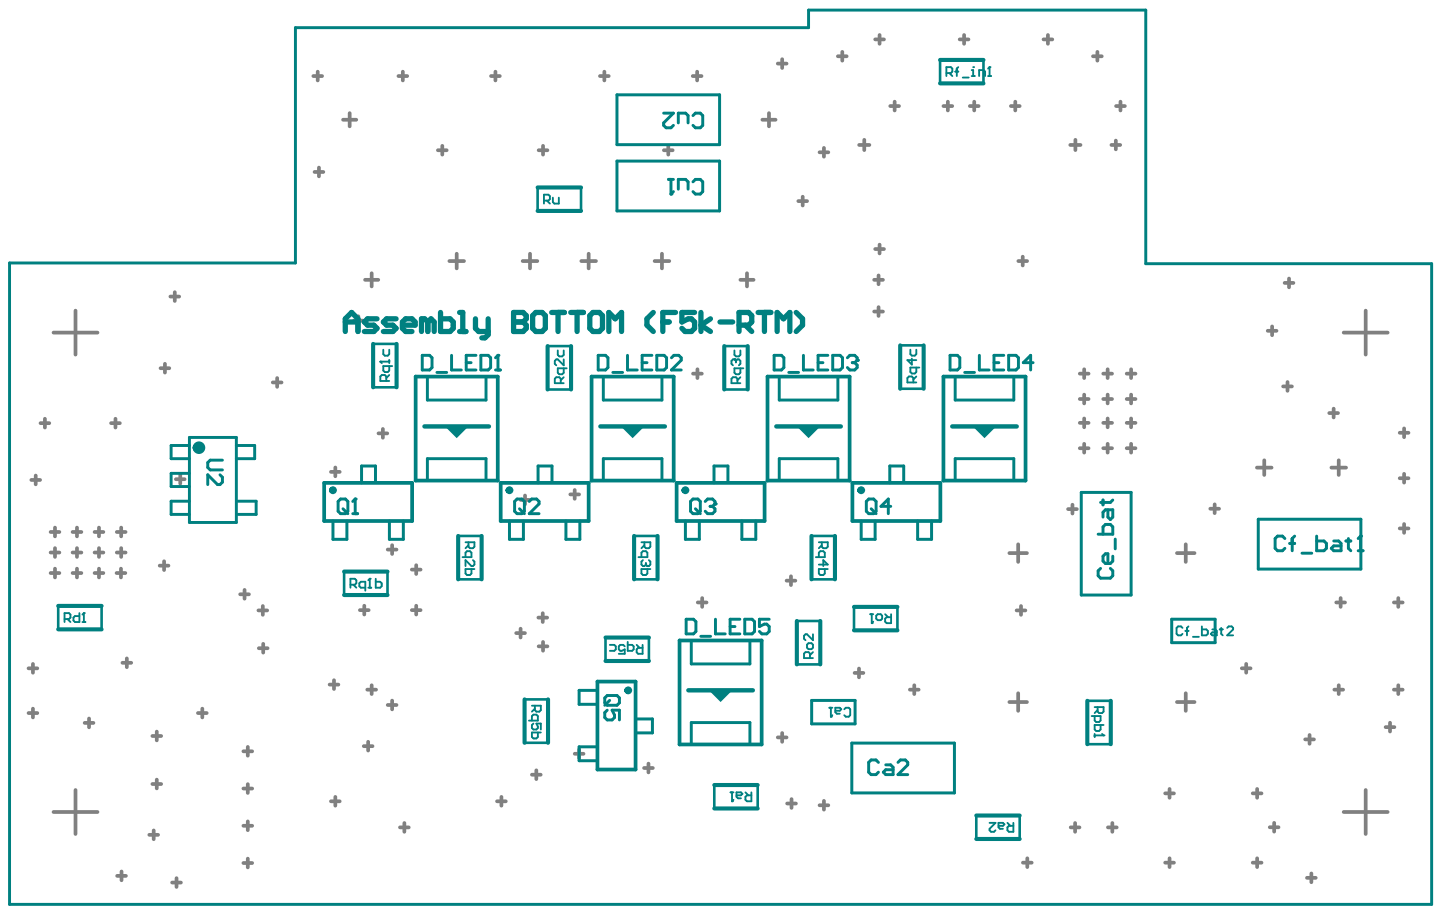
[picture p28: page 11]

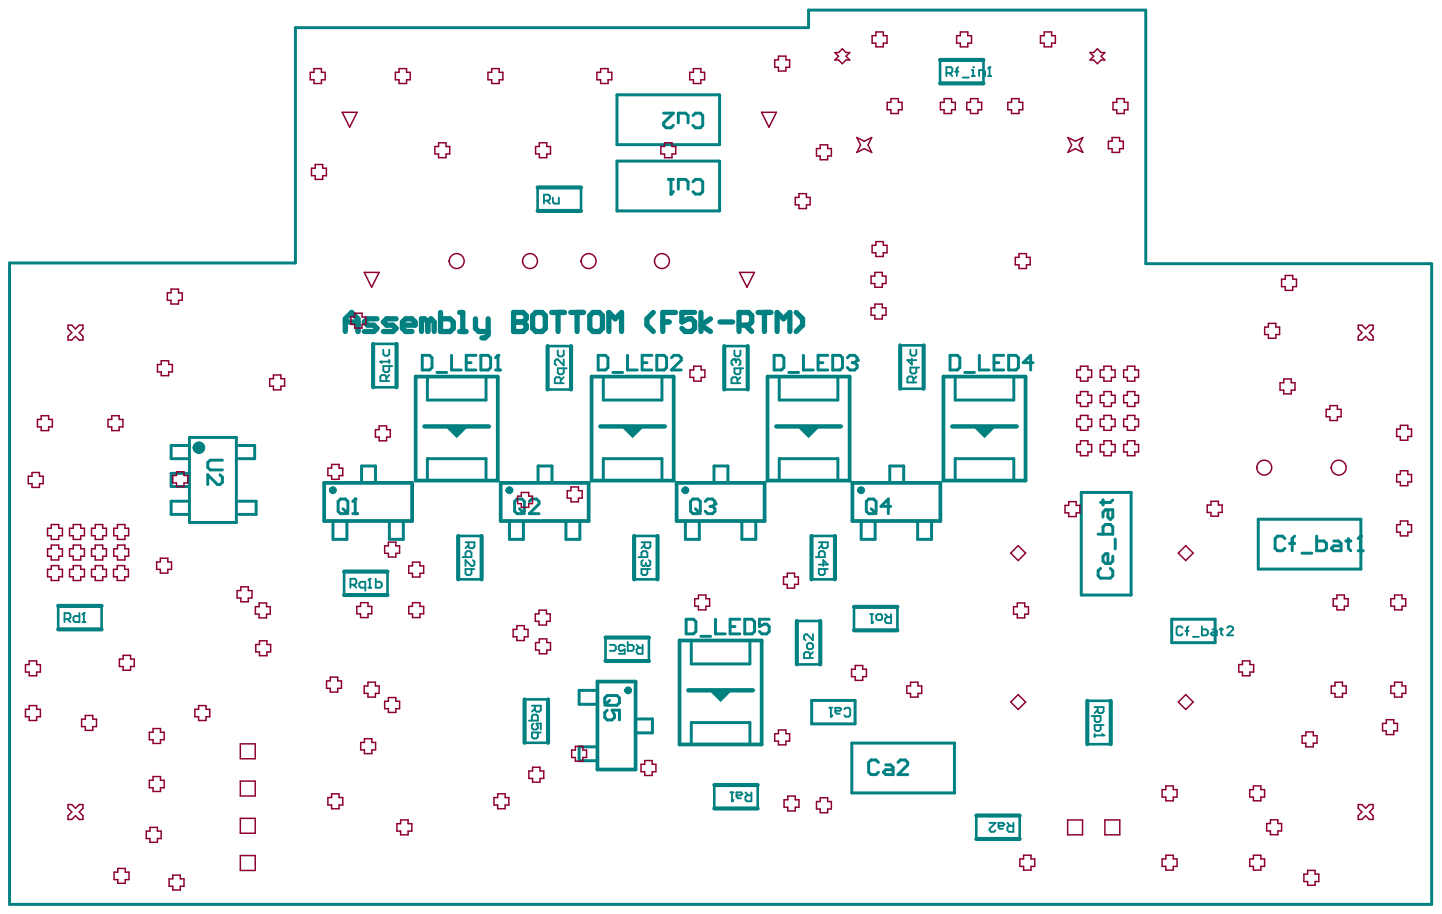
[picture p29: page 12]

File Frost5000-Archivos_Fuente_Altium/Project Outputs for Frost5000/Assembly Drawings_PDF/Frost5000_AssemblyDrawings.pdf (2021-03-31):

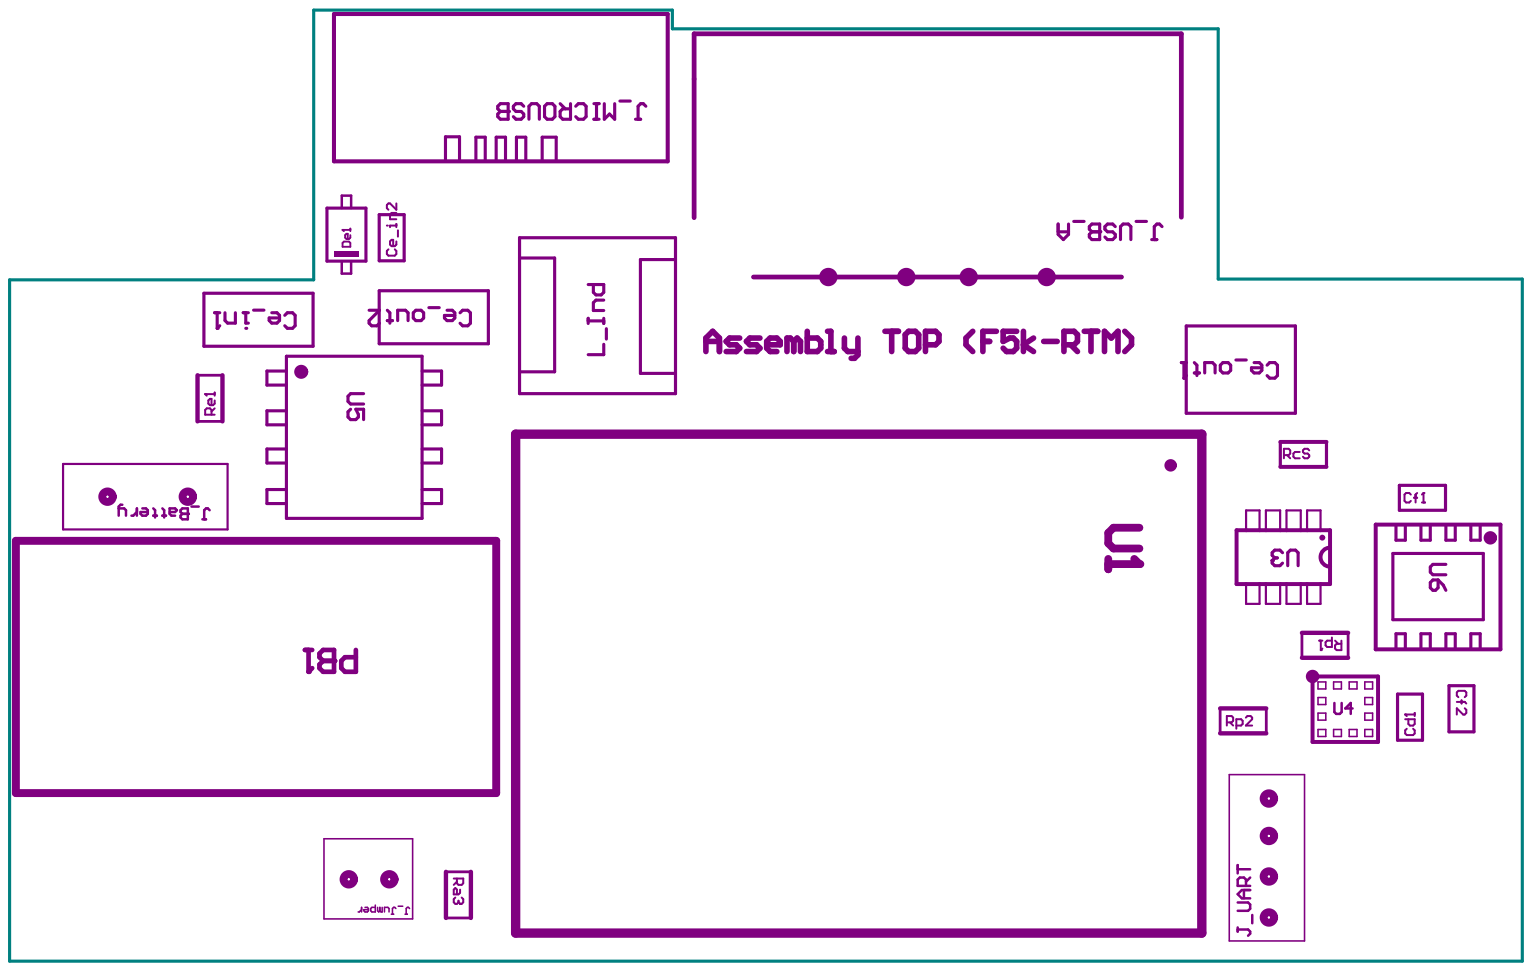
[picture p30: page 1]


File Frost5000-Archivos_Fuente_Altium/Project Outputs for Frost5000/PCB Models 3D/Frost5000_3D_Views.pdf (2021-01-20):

A

B


View from Top side (Scale 3.8)

View from Bottom side (Scale 3.8)

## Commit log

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2020-05-13 Cargado Todos los archivos del Summits7 ya que muchos son similares. Entre ellos se cargan las librerias de Schematic y PCB
    [ABM8-26MHz.STEP, AP65111A-SOT23-6.step, Cap0603.step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]
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2020-06-02 Cargado (Symbol y Footprint) y Testeado: - Cargador de Batería 3A BQ25606 - Descargador (Fuente Boost) TP561023
    Limpiado del Repositorio Archivos del Summits que no corresponden al FROST
    [AP65111A-SOT23-6.step, BQ25606-VQFN24.step, Fotodiodo_VBPW34S.step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]
2020-06-03 - Modificado Inductor por el Correcto - Agregado Diodo Zener
    [Frost5000Beta_LIB_Otros_PCB.PcbLib, Frost5000Beta_LIB_Otros_Sch.SchLib, Frost5000Beta_LIB_Pasivos_Sch.SchLib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]
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2020-06-08 Cargado casi todo el schematic. Falta: - INA219 - Acelerometro - LEDS ver donde ponerlos con los gpio disponibles - Faltan algunas conexiones como el estado de carga del BQ25606
    [Frost5000Beta_LIB_Integrados_PCB.PcbLib, Frost5000Beta_LIB_Integrados_Sch.SchLib, Frost5000Beta_Sch.SchDoc]
2020-06-09 -Se hizo una mejor redistribución del schematic porque se estaba apilando todo y estaba un poco confuso. -Se agregó INA219 al schematic -Se agregó al proyecto el nuevo acelerómetro LSM303AGR que falt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
    [Frost5000Beta_LIB_Integrados_PCB.PcbLib, Frost5000Beta_LIB_Integrados_Sch.SchLib, Frost5000Beta_Sch.SchDoc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]
2020-06-10 - Se hizo añadió al schematic el circuito del acelerometro LSM303AGR - Se añadió a la librería el acelerometro ICM-20948 por las dudas haya probelmas de stock con el LSM303AGR
    [Frost5000Beta_LIB_Integrados_PCB.PcbLib, Frost5000Beta_LIB_Integrados_Sch.SchLib, Frost5000Beta_Sch.SchDoc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]
2020-06-11 - Agregado resistencia PullUp al GPIO2 - Agregado como van a ir los pines de GPIOs de LEDS y STATUS BATERIA - Modificado un poco el schematic del led aunque falta
    [Frost5000Beta_Sch.SchDoc]
2020-06-26 - Cargado nuevo LDO 3.3V LM1117-3.3 de Texas que es mas pequeño - Cargado nuevo LED - Cargados los STEPS de los USB (El USB A esta mal hay q corregir) - Corregido Schematic, cambiado el nuevo LDO, lo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
    [Frost5000Beta_LIB_Conectores_PCB.PcbLib, Frost5000Beta_LIB_Integrados_PCB.PcbLib, Frost5000Beta_LIB_Integrados_Sch.SchLib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]
2020-06-29 - Modificado Antena y puente Pi - Modificados todos los Designators para que no haya conflictos
    [Frost5000Beta_LIB_Conectores_PCB.PcbLib, Frost5000Beta_LIB_Otros_PCB.PcbLib, Frost5000Beta_LIB_Otros_Sch.SchLib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]
2020-06-29 Corregido Errores de Compilación del Schematic
    [Frost5000Beta_LIB_Otros_Sch.SchLib, Frost5000Beta_Sch.SchDoc]
2020-06-29 - Implementación del tamaño del PCB - Corregido errores menores en footprint de algunos componentes
    [Frost5000Beta_LIB_Conectores_PCB.PcbLib, Frost5000Beta_LIB_Conectores_Sch.SchLib, Frost5000Beta_PCB.PcbDoc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]
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2020-07-06 Listo el diseño. - Arreglado los planos de masa. - Corregido valores de resistencia de los Leds. - Agregados los test points para modificar resistencias y agregar el Sleep. - Agregada la conexión al 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
    [Frost5000Beta_LIB_Otros_PCB.PcbLib, Frost5000Beta_LIB_Otros_Sch.SchLib, Frost5000Beta_PCB.PcbDoc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]
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2020-07-08 Check 1: - Actualizados valores de capacitores del Cristal por unos acordes al datasheet
    [Frost5000Beta_PCB.PcbDoc, Frost5000Beta_Sch.SchDoc]
2020-07-08 Check 2: - Cambio resistencia Ra3 de 500 a 499 acordes al datasheet Hardware Guideline ESP8266EX - Normalización de todos los valores de resistencia para evitar confusiones
    [Frost5000Beta_PCB.PcbDoc, Frost5000Beta_Sch.SchDoc]
2020-07-08 Check2.3: - La placa ya no tiene bordes metalicos en la parte de los Holes
    [Frost5000Beta_LIB_Otros_PCB.PcbLib, Frost5000Beta_PCB.PcbDoc]
2020-07-09 Check4: - Resistencia Ra2 cambiada de 220 a 200 - Room eliminada - Agregada Via GND cerca de Res 12K - Se quitaron todas las pistas debajo del Crystal
    [Frost5000Beta.PrjPcb, Frost5000Beta_PCB.PcbDoc, Frost5000Beta_Sch.SchDoc]
2020-07-10 Check5: - Retocado un poco el Plano de Masa, se agregaron algunas vías - Se retocó el Schematic cambiando todo al idioma inglés y detallando componentes. - Se agregaron los valores de los L de fuente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
    [Frost5000Beta_PCB.PcbDoc, Frost5000Beta_Sch.SchDoc]
2020-07-11 Check6: - Actualizados los Nombres de los USB . Actualizado el schematic de los USB para incluir masa que estaba dando discrepancias entre sch y PCB.
    [Frost5000Beta_LIB_Conectores_Sch.SchLib, Frost5000Beta_PCB.PcbDoc, Frost5000Beta_Sch.SchDoc]
2020-07-12 Check7: - Se puso a masa el A0 y A1 ya que de esta forma se define la direccion de memoria donde se alojaran los registros, aunque tambien funciona flotante, es mas seguro de esta forma. - Se quitó u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
    [Frost5000Beta_PCB.PcbDoc, Frost5000Beta_Sch.SchDoc]
2020-07-14 Check 8 -Ultimo Check: - Se comprobo los pads de todos los componentes. - Se corrigieron detalles muy menores
    [Frost5000Beta_LIB_Integrados_Sch.SchLib, Frost5000Beta_PCB.PcbDoc]
2020-07-15 Generacion de Outputs - Parte 1: - Generación de Archivo OUTPUT - Se generó PDF del Schematic - Se generó Archivo STEP en 3D del PCB - Se generó un PDF con los layers del PCB
    - Se agregó un nuevo layer (Borde de Linea) al proyecto ya que es útil para el PDF de los layers
    [Frost5000Beta.PrjPcb, Frost5000Beta_PCB.PcbDoc, Frost5000Beta_PCB.step]
2020-07-15 Generacion de Outputs - Parte 2: - Los Assembly Drawings estaban incompletos asi que se procedió a completar componente por componente para que el Fabricante tenga mas claro todo a la hora de armar l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
    [Frost5000Beta.PrjPcb, Frost5000Beta_LIB_Conectores_PCB.PcbLib, Frost5000Beta_LIB_Conectores_Sch.SchLib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]
2020-07-15 Generacion de Outputs - Parte 3: - Los Assembly Drawings estaban incompletos asi que se procedió a completar componente por componente para que el Fabricante tenga mas claro todo. - Corregido un poqu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
    [Frost5000Beta_LIB_Integrados_PCB.PcbLib, Frost5000Beta_LIB_Otros_PCB.PcbLib, Frost5000Beta_LIB_Pasivos_PCB.PcbLib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]
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2020-12-18 Corrección de Silkscreens: Corregido tamaño de los Designators. Corregidos los Silkscreens de los dispositivos que se molestaban entre sí (Por ejemplo USB y Switch) Solo un par de componentes fueron 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
    [Frost5000Beta_LIB_Conectores_PCB.PcbLib, Frost5000Beta_LIB_Otros_PCB.PcbLib, Frost5000Beta_Sch.SchDoc]
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
